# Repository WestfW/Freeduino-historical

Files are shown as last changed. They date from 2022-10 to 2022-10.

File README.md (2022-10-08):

Freeduino-historical:
Files and history of the ~2007 "Freeduino" project.

# <div align="center">The Freeduino Story</div>
### <div align="center">by Bill Westfield (WestfW)</div>
---

Back in about 2007, Arduino was small but rapidly growing.
Diecilmilla had been released, but the publication of its CAD files
was behind, and there was noise that perhaps the "open source
hardware" days of Arduino were behind them.  Supplies of real Arduinos
were a bit short, and there were a couple of users who were upset that
they could not manufacture their own "in bulk" for classroom
situations, and several vendors that were upset that they were unable
to negotiate the ability to sell genuine Arduinos with Arduino
themselves (or at least, not at terms that they liked.  (But I think
mostly just due to supply constraints.))

Anyway, "we" wound up with one particularly passionate user (Daniel),
one motivated vendor (NKC Electronics), a low-level guy with some
EE and low-level background looking to improve his EAGLE skills (Me!
(WestfW)), and a couple of other contibuters (notably Solarbotics and
Scott), determined to create a "truly open-source" version of the
Arduino without any of the restrictions that the Arduino Company
seemed to be considering (not even a Trademark!)

We never met.  There was much discussion via email, and a forum that
Daniel set up.  Eventually, I had four EAGLE designs mostly similar to
the Duemilanove - one using mostly throughole components, and one each
using 0603, 0805, an 1206 SMT components.  I thought we were still
discussing things, and suddenly NKC piped up with "Well, I've ordered
100 bare PCBs of each version, and we'll see how they go"!  I was a
bit shocked; I had been putting a lot of time into the project, but
JUST time.  Ordering 400 PCBs represented "real money"!

Once a couple of boards of each type had been assembled (at/by NKC), a
decision was made to focus on the through-hole design, so that it
could be sold as a kit.  This would both appeal the the people coming
at Arduino from the Electronics Hobbyist side of the world, as well as
saving some manufacturing costs (this was well before "cheap SMT
assembly services" were common.)  Additional revisions to the design
were made with this in mind.  For example, the board was expanded
slightly to make more room, and the voltage regulator was changed to a
full-sized TO220.

---

I guess the design was a success.  NKC sold Freeduino kits for quite a
few years, Solarbotics sold their (somewhat diffrent) design, and
... various PCBs appeared from strange places, complete with the
little "PCB by WestfW" trace in the corner.  Also, Arduino
re-committed to Open-source principles, and apparently started
accepting more vendors as resellers, making the design somewhat
superfulous.  And then the cheap clones from China appeared, along
with cheaper PCB services, a more formal OSHW movement, and newer,
better, and lower-cost designs showed up from ... lots of places.  I
think Freeduino is no longer *necessary*.  But I like to think that it
was a useful "nudge" toward the way things are today.

---

See also:

https://forum.arduino.cc/t/arduino-vs-freeduino-what-is-the-difference/24209/2
https://forum.arduino.cc/t/freeduino-universe/6800/
https://forum.arduino.cc/t/diecimila-pcb-files/2116/

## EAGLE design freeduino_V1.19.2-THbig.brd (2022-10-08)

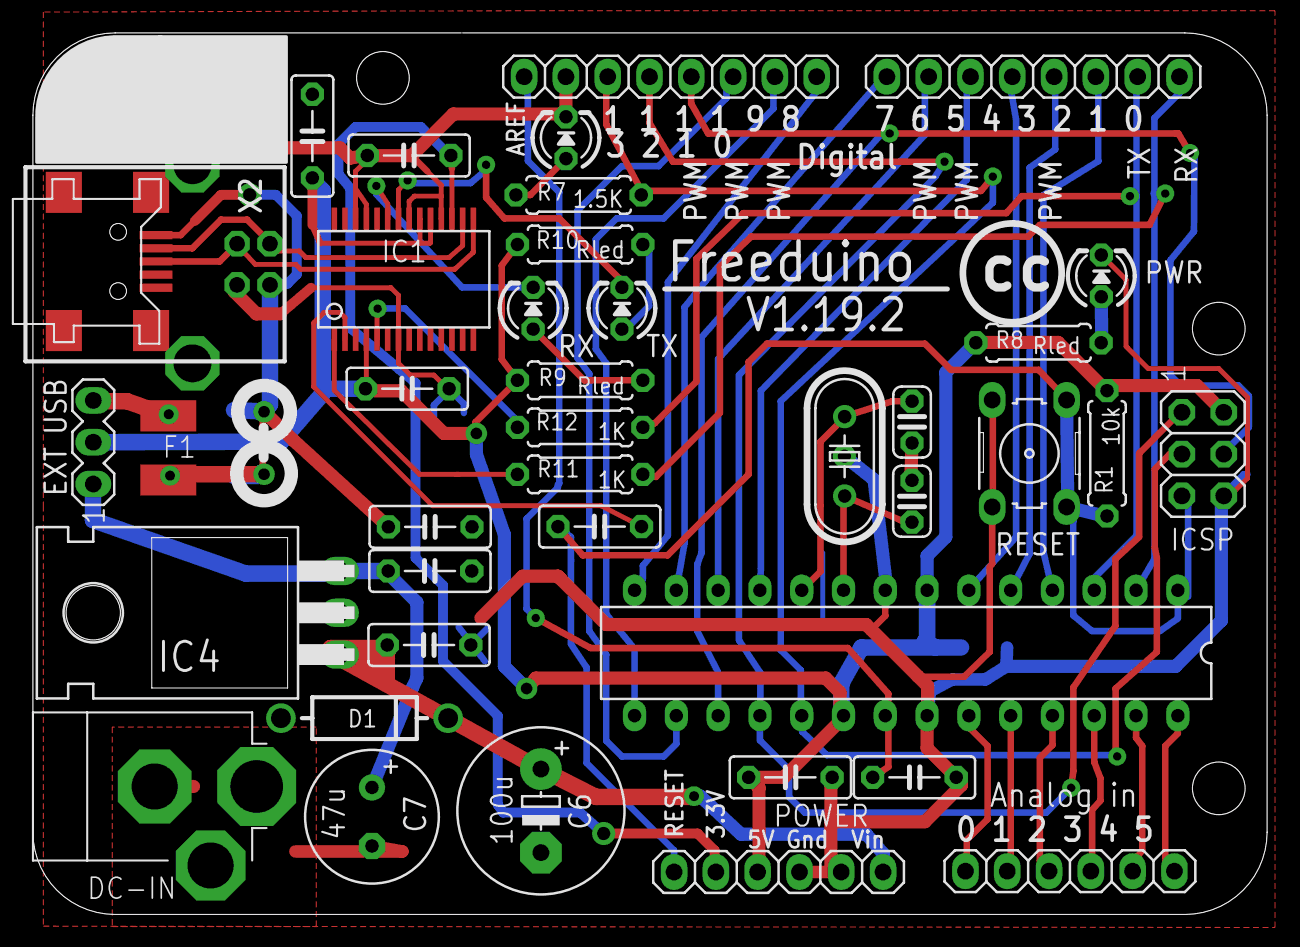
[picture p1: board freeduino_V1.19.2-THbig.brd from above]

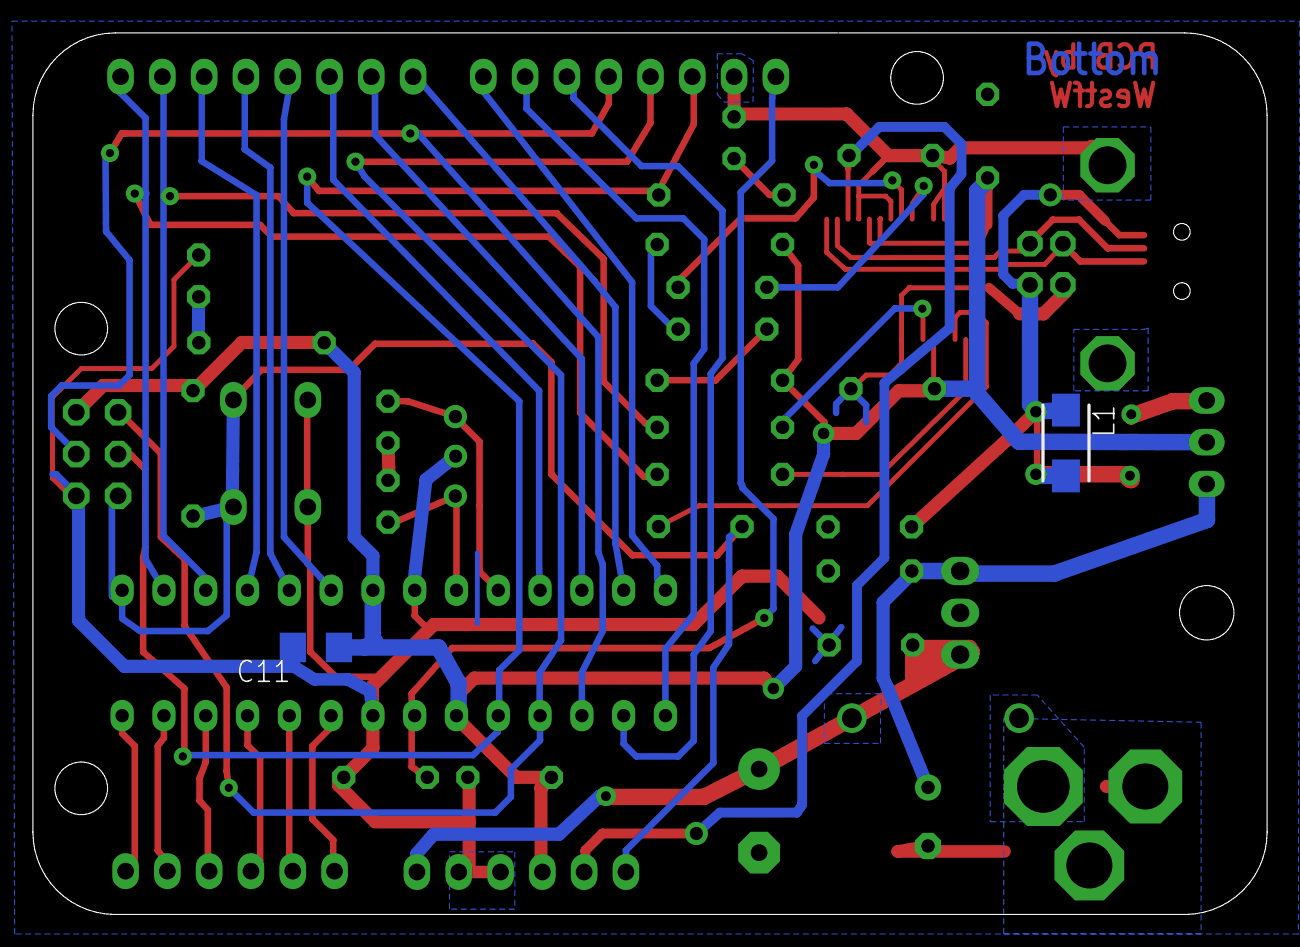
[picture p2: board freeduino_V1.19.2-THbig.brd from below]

Board: 2 copper layers, 75.0 x 53.6 mm, 44 parts (2 on the bottom side), 43 nets.

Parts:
BVALUE: ATMEGA168; DIL28-3
C1, C5, C8, C9, C10, C12: 100n; C050-025X075
C2, C3: 22pf; C025-024X044
C4: 10n; C050-025X075
C6: 100u; E5-10,5
C7: 47u; E3,5-8
C11: 100n; C1206
C13: 4u7; C050-025X075
CRS: 100n; C050-025X075
D1: 1N4004; DIODE-0.4
F1: PTC1812; C1812
FB1: FB3.8
IC1: FT232RL; SSOP28DB
IC4: 7805T; TO220H
ICSP: ICSP; 2X03
J1, J3: 1X08
J2: 1X06
JP1: 1X06
L1: SM-B5
P13: LED3MM
PWR: LED3MM
Q1: 16Mhz; HC49U-V
R1: 10k; 0207/7
R7: 1.5K; 0207/7
R8, R9, R10: Rled; 0207/7
R11, R12: 1K; 0207/7
RESET: B3F-10XX
RX: LED3MM
SV1: MA03-1
TX: LED3MM
U$1: DC-IN; 4UCON-POWER-JACK
U$2: MINIUSB; UX60A-MB-5SY
U$3: CC-LOGO
X2: USB-WSHIELDPADS

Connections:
+5V: BVALUE.7, BVALUE.20, C1.1, C10.2, C11.2, C13.2, IC1.4, IC1.19, IC1.20, ICSP.2, JP1.3, R1.2, R8.1, R9.1, R10.1, SV1.2
AREF: BVALUE.21, C9.1, J1.8
GND: BVALUE.8, BVALUE.22, C1.2, C2.1, C3.1, C4.1, C5.1, C6.-, C7.-, C8.2, C9.2, C10.1, C11.1, C12.1, C13.1, IC1.7, IC1.18, IC1.21, IC1.25, IC1.26, IC4.2, ICSP.6, J1.7, JP1.4, JP1.5, P13.K, PWR.K, RESET.3, RESET.4, U$1.1, U$1.3, U$2.5, X2.4, X2.SH1, X2.SH2
M8RXD: IC1.1, R11.1
M8TXD: IC1.5, R12.1
unnamed: BVALUE.15, J1.2
unnamed: PWR.A, R8.2
unnamed: IC1.23, RX.K
unnamed: BVALUE.9, C2.2, Q1.2
unnamed: F1.2, SV1.3
unnamed: D1.A, U$1.2
unnamed: IC1.16, U$2.2, X2.2
unnamed: BVALUE.4, J3.3
unnamed: BVALUE.5, J3.4
unnamed: BVALUE.6, J3.5
unnamed: BVALUE.11, J3.6
unnamed: BVALUE.12, J3.7
unnamed: BVALUE.13, J3.8
unnamed: BVALUE.23, J2.1
unnamed: BVALUE.24, J2.2
unnamed: BVALUE.25, J2.3
unnamed: BVALUE.26, J2.4
unnamed: BVALUE.27, J2.5
unnamed: BVALUE.28, J2.6
unnamed: BVALUE.3, J3.2, R12.2
unnamed: BVALUE.16, J1.3
unnamed: IC1.15, U$2.3, X2.3
unnamed: BVALUE.18, ICSP.1, J1.5
unnamed: BVALUE.14, J1.1
unnamed: IC1.22, TX.K
unnamed: BVALUE.10, C3.2, Q1.1
unnamed: P13.A, R7.1
unnamed: R10.2, TX.A
unnamed: C4.2, F1.1, FB1.P$1, FB1.P$2, L1.1, L1.2, U$2.1, X2.1
unnamed: R9.2, RX.A
unnamed: CRS.1, IC1.2
unnamed: BVALUE.17, ICSP.4, J1.4
unnamed: BVALUE.2, J3.1, R11.2
RESET: BVALUE.1, CRS.2, ICSP.5, JP1.1, R1.1, RESET.1, RESET.2
SCK: BVALUE.19, ICSP.3, J1.6, R7.2
VCC: C7.+, C12.2, IC4.3, SV1.1
VCC3V0: C8.1, IC1.17, JP1.2
VIN: C5.2, C6.+, D1.C, IC4.1, JP1.6
